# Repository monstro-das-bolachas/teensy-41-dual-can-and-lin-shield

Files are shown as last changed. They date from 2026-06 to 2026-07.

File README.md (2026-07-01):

# OBDee-Wan CANobi

> Open-hardware automotive bus interface for CAN FD, classic CAN, LIN, and K-line exploration.

OBDee-Wan CANobi is a Teensy 4.1 based vehicle-network tool for hackers, makers, reverse engineers, EV converters, and curious learners who want hardware they can inspect and understand.

It is designed as a practical bridge between a laptop and a vehicle or bench module: powerful enough for real CAN FD/LIN/K-line experiments, but documented as a teaching project rather than a black box.






## At a glance

| Area | Current R11 target |
| --- | --- |
| Host | Teensy 4.1 |
| CAN FD | 2 external CAN FD controller paths |
| Transceivers | Dual CAN FD transceivers |
| Other buses | LIN / K-line support path |
| Vehicle connection | OBD pigtail-friendly wiring, not a direct-plug dongle |
| Configuration | DIP-switch selectable routing options |
| CAD | KiCad hardware source and generated fabrication packages |
| Readiness | Bare-PCB prototype candidate for bench bring-up |

## What you can use it for

- CAN FD experimentation and learning
- Classic CAN diagnostics and reverse engineering
- LIN and K-line bench experiments
- EV conversion support tooling
- Custom diagnostic interface development
- Teaching automotive networks with inspectable hardware
- Bench testing ECUs, modules, sensors, and harness fragments

## Current status: R11 prototype manufacturing candidate

R11 may be ordered as a small bare-PCB prototype batch for bench bring-up.

It is not approved for direct vehicle testing yet.

### Active release package

`revisions/00_WORK_R11_TRUE_DUAL_CANFD/release/R11_PROTOTYPE_MANUFACTURING_CANDIDATE_20260630/`

### Manufacturer upload ZIP

`revisions/00_WORK_R11_TRUE_DUAL_CANFD/release/R11_PROTOTYPE_MANUFACTURING_CANDIDATE_20260630/package/JLCPCB_PCBWAY_UPLOAD_R11_MINIMAL_GERBERS_ONLY_20260630.zip`

SHA256:

`434dedf475bb3443f1ffa6384541426fcef9cf96a792c1744b9c1bb7ff68faa8`

### Verification summary

| Check | Result |
| --- | --- |
| KiCad CLI PCB DRC | 0 violations |
| Footprint errors | 0 |
| Known residual | 1 GND zone-to-zone report at 1.0000 mm / 1.0000 mm |
| Gerber/drill export | Successful |
| GND continuity | Visually confirmed in KiCad after refill/highlight |
| Vehicle-use approval | Not yet; bench validation required first |

The remaining GND item is a reviewed KiCad zone-report artifact for prototype PCB ordering. It is not a blanket safety approval for vehicle connection.

## Safety first

Vehicle electrical systems can damage tools, modules, or the car if connected incorrectly. Treat every first assembly as experimental hardware.

Before connecting to a vehicle:

1. Inspect the bare PCB.
2. Check for rail shorts with a multimeter.
3. Assemble and test the power section first.
4. Power up from a current-limited bench supply.
5. Verify OBD/pigtail pin mapping manually.
6. Confirm DIP-switch defaults and intended routing.
7. Test CAN/LIN/K behavior on bench modules first.
8. Use fusing and current limiting for any later vehicle test.

## Repository map

| Path | Purpose |
| --- | --- |
| `README_START_HERE.txt` | Short navigation and safety guide |
| `CURRENT_STATUS.md` | Current revision status, ordering notes, and verification summary |
| `revisions/00_WORK_R11_TRUE_DUAL_CANFD/` | Active R11 prototype candidate source and release package |
| `revisions/00_ACTIVE_R10_TRUE_DUAL_CANFD/` | Previous R10 archive, not for fabrication |
| `revisions/01_R9_CLASSIC_CAN_ARCHIVE/` | Historical R9 classic-CAN reference |
| `LICENSE` | Main hardware license: CERN-OHL-P-2.0 |
| `LICENSES/` | Full license texts and license split documentation |

## Recommended first order

For the first prototype batch, use conservative bare-board settings:

| Option | Recommendation |
| --- | --- |
| Quantity | 5 or smallest economical batch |
| Layers | 2 |
| Material | FR-4 |
| Thickness | 1.6 mm |
| Copper | 1 oz |
| Surface finish | Standard low-cost prototype finish is acceptable |
| Electrical test | Yes |
| Assembly | No; hand-assemble and validate first |

## Naming note

The project name is a small joke:

OBDee-Wan CANobi: an OBD/CAN interface that helps you feel disturbances in the bus.

## License

This project is open source and open hardware.

| Content | License |
| --- | --- |
| Hardware design files, KiCad sources, PCB/manufacturing files | CERN-OHL-P-2.0 |
| Firmware, scripts, and software | MIT |
| Documentation | CC-BY-4.0 |

You are free to study, modify, build, remix, and share this project. Attribution is required where applicable: please credit the original project and author when reusing or publishing derivative work.

See `LICENSES/README.md` for the full license split and SPDX identifiers.

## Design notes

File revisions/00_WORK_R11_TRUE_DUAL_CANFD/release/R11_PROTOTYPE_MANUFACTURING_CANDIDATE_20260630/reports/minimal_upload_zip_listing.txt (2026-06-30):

Archive:  /home/kali/teensy-r9-publish/revisions/00_WORK_R11_TRUE_DUAL_CANFD/release/R11_PROTOTYPE_MANUFACTURING_CANDIDATE_20260630/package/JLCPCB_PCBWAY_UPLOAD_R11_MINIMAL_GERBERS_ONLY_20260630.zip
  Length      Date    Time    Name
---------  ---------- -----   ----
   331847  2026-06-30 16:31   teensy-41-true-dual-canfd-lin-r11_JARVIS_ROUTED_CLEAN_V2_GND_STITCH-F_Cu.gtl
   207463  2026-06-30 16:31   teensy-41-true-dual-canfd-lin-r11_JARVIS_ROUTED_CLEAN_V2_GND_STITCH-B_Cu.gbl
     6726  2026-06-30 16:31   teensy-41-true-dual-canfd-lin-r11_JARVIS_ROUTED_CLEAN_V2_GND_STITCH-F_Mask.gts
     4547  2026-06-30 16:31   teensy-41-true-dual-canfd-lin-r11_JARVIS_ROUTED_CLEAN_V2_GND_STITCH-B_Mask.gbs
   138018  2026-06-30 16:31   teensy-41-true-dual-canfd-lin-r11_JARVIS_ROUTED_CLEAN_V2_GND_STITCH-F_Silkscreen.gto
    11956  2026-06-30 16:31   teensy-41-true-dual-canfd-lin-r11_JARVIS_ROUTED_CLEAN_V2_GND_STITCH-B_Silkscreen.gbo
      696  2026-06-30 16:31   teensy-41-true-dual-canfd-lin-r11_JARVIS_ROUTED_CLEAN_V2_GND_STITCH-Edge_Cuts.gm1
     3138  2026-06-30 16:31   teensy-41-true-dual-canfd-lin-r11_JARVIS_ROUTED_CLEAN_V2_GND_STITCH.drl
     5463  2026-06-30 16:31   teensy-41-true-dual-canfd-lin-r11_JARVIS_ROUTED_CLEAN_V2_GND_STITCH-job.gbrjob
---------                     -------
   709854                     9 files

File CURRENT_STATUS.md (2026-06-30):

# Current project status

Last checked/updated: 2026-06-30

## Executive summary

The active hardware revision is now **R11 true dual CAN FD + LIN/K prototype manufacturing candidate**.

R11 may be ordered as a small bare-PCB prototype batch for bench bring-up. It is **not approved for direct vehicle testing** until assembled boards pass continuity, power, pin-map, and fused OBD bench checks.

## Active R11 files

Active working revision folder:

- `revisions/00_WORK_R11_TRUE_DUAL_CANFD/`

Clean release package folder:

- `revisions/00_WORK_R11_TRUE_DUAL_CANFD/release/R11_PROTOTYPE_MANUFACTURING_CANDIDATE_20260630/`

Active KiCad source:

- `revisions/00_WORK_R11_TRUE_DUAL_CANFD/kicad/teensy-41-true-dual-canfd-lin-r11_JARVIS_ROUTED_CLEAN_V2_GND_STITCH.kicad_pcb`
- `revisions/00_WORK_R11_TRUE_DUAL_CANFD/kicad/teensy-41-true-dual-canfd-lin-r11_JARVIS_ROUTED_CLEAN_V2_GND_STITCH.kicad_pro`

JLCPCB / PCBWay upload ZIP:

- `revisions/00_WORK_R11_TRUE_DUAL_CANFD/release/R11_PROTOTYPE_MANUFACTURING_CANDIDATE_20260630/package/JLCPCB_PCBWAY_UPLOAD_R11_MINIMAL_GERBERS_ONLY_20260630.zip`

Full release ZIP:

- `revisions/00_WORK_R11_TRUE_DUAL_CANFD/release/R11_PROTOTYPE_MANUFACTURING_CANDIDATE_20260630/package/R11_PROTOTYPE_MANUFACTURING_CANDIDATE_20260630_FULL_RELEASE.zip`

## R11 verification

KiCad CLI DRC was run against the active board and the clean release-copy board.

Reports:

- `revisions/00_WORK_R11_TRUE_DUAL_CANFD/release/R11_PROTOTYPE_MANUFACTURING_CANDIDATE_20260630/reports/R11_PROTOTYPE_CANDIDATE_DRC.rpt`
- `revisions/00_WORK_R11_TRUE_DUAL_CANFD/release/R11_PROTOTYPE_MANUFACTURING_CANDIDATE_20260630/reports/R11_PROTOTYPE_CANDIDATE_CLEAN_RELEASE_COPY_DRC.rpt`

Result:

- DRC violations: 0
- Known residual: 1 GND F.Cu/B.Cu zone-to-zone unconnected report at 1.0000 mm / 1.0000 mm
- Footprint errors: 0
- Gerber/drill export: successful
- GND continuity: visually confirmed in KiCad after zone refill/highlight

The residual GND item is treated as a reviewed KiCad zone-report artifact for prototype PCB ordering, not as approval for vehicle use.

## R11 prototype ordering guidance

Order only a small bare-PCB batch first:

- 2 layers
- FR-4
- 1.6 mm
- 1 oz copper
- 5 pieces or smallest economical batch
- electrical test enabled
- no assembly for first order

Before vehicle testing:

1. Inspect bare PCBs.
2. Check GND continuity and rail shorts with a multimeter.
3. Assemble power section first.
4. Power from a current-limited bench supply.
5. Verify OBD/pigtail pin mapping with a multimeter.
6. Verify DIP switch safe/default positions.
7. Test CAN/LIN/K behavior on bench hardware before a fused OBD vehicle connection.

## R10/R9 status

R10 remains archived as `NOT FOR FAB` after external review. R9 remains historical/reference material only and is not true dual CAN FD.

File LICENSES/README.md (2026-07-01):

# Licensing

This project is open source and open hardware.

Copyright (c) 2026 Nuno Silva.

## License split

- Hardware design files, KiCad sources, PCB manufacturing outputs, and hardware documentation describing the design as source: `CERN-OHL-P-2.0`
- Firmware, scripts, examples, and other software source code: `MIT`
- Human-facing documentation, guides, diagrams, notes, and explanatory text: `CC-BY-4.0`

## What this means

You are welcome to study, build, modify, remix, repair, sell, and share derivatives of this project.

The main thing I ask — and the licenses require where applicable — is attribution: please credit the original project and author when reusing or publishing derivative work.

## SPDX identifiers

Use these SPDX identifiers when adding new files:

```text
SPDX-License-Identifier: CERN-OHL-P-2.0
```

for hardware design files.

```text
SPDX-License-Identifier: MIT
```

for firmware/software.

```text
SPDX-License-Identifier: CC-BY-4.0
```

for documentation.

## Full license texts

- `LICENSE` — CERN-OHL-P-2.0, the main repository hardware license.
- `LICENSES/CERN-OHL-P-2.0.txt`
- `LICENSES/MIT.txt`
- `LICENSES/CC-BY-4.0.txt`

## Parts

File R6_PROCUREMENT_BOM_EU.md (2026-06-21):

# R6 EU Procurement BOM

Status: procurement BOM for the corrected R6 manufacturing candidate.

Use this with the R6 board files, not the older R5 files.

Primary fabrication ZIP:

- `r6_complete_power_fabrication_minimal_gerbers.zip`

Procurement CSV:

- `BOM_R6_PROCUREMENT_EU.csv`

## Why R6 replaced R5

During BOM audit I found that R5 was DRC-clean but did not include the required external LM2596 buck-regulator components. R6 corrects this by adding:

- L1 buck inductor
- D2 Schottky catch diode
- C1 input electrolytic capacitor
- C3 output electrolytic capacitor
- C2/C4 ceramic input/output capacitors
- C5/C6/C7 local decoupling capacitors for CAN/LIN ICs
- R1 10k pull-up for the TLIN1029 open-drain LIN RXD output

R6 also changes the selected communication ICs to parts that are better aligned with Teensy 4.1 3.3 V logic:

- U2/U3: Microchip MCP2562FD-E/SN CAN transceivers with VIO on pin 5 connected to Teensy +3.3 V.
- U4: TI TLIN1029DRQ1 LIN transceiver, whose RXD is open-drain and pulled up to +3.3 V by R1.

## Suppliers

The BOM uses exact manufacturer part numbers. Suitable Europe-capable suppliers include:

- Mouser Europe
- DigiKey Europe
- Farnell / element14
- RS Components Europe
- TI store / MicrochipDirect where appropriate
- Pimoroni or other European PJRC/SparkFun distributors for Teensy 4.1

For best results, paste the exact MPN from the CSV into the supplier search box. Supplier stock numbers change more often than manufacturer part numbers.

## Critical no-substitution rules

Do not blindly substitute these parts:

- U2/U3 CAN transceivers: must have VIO/3.3 V I/O support on pin 5. Do not use MCP2551, TJA1050, or plain 5 V-only CAN transceivers.
- U4 LIN transceiver: must match TLIN1029DRQ1 SOIC-8 pinout if using this PCB.
- U5 regulator: must be fixed 5 V LM2596S-5.0 in TO-263-5/D2PAK-style package, not the adjustable version, unless the PCB is redesigned.
- SW1/SW2 DIP switches: must be 8-position SPST through-hole DIP, 2.54 mm pitch, 7.62 mm row spacing.
- C1/C3 electrolytics: observe polarity and keep diameter/lead pitch compatible with the footprint.

## Assembly order recommendation

1. Solder power/protection parts first: F1, D1, U5, L1, D2, C1, C2, C3, C4.
2. Bench-test the board from a current-limited 12 V supply.
3. Verify +5 V at TP2 and +3.3 V from the Teensy socket only after the Teensy is installed/powered appropriately.
4. Solder R1, C5/C6/C7, U2/U3/U4.
5. Solder SW1/SW2 and optional J2.
6. Install/socket Teensy 4.1 last.
7. Verify OBD pigtail pin numbering with a multimeter before connecting to a vehicle.

## Vehicle-use warning

This is still a first real hardware prototype. Even with a DRC-clean PCB and procurement BOM, test on the bench before connecting to a vehicle. Start with read-only/silent CAN firmware and no CAN transmission.

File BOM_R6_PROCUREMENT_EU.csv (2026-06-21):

Designator | Qty | Category | Exact MPN / Orderable Part | Manufacturer | Package / Footprint | Primary EU-capable supplier | Search / Supplier note | Substitution constraints | Assembly note
U1 | 1 | MCU module | DEV-16771 / Teensy 4.1 | SparkFun / PJRC | Teensy 4.1 module | Digikey / Mouser / Pimoroni / PJRC | Search supplier for DEV-16771 or PJRC Teensy 4.1 | Must be Teensy 4.1 not Teensy 4.0; socket recommended | Install after verifying 5V rail
U2 U3 | 2 | CAN transceiver | MCP2562FD-E/SN | Microchip | SOIC-8 3.9x4.9mm P1.27 | Mouser EU / DigiKey EU | Search exact MPN MCP2562FD-E/SN | Must have VIO pin on pin 5 for 3.3V Teensy I/O; do not substitute MCP2551/TJA1050 | Tin SOIC pads lightly; observe pin 1
U4 | 1 | LIN transceiver | TLIN1029DRQ1 | Texas Instruments | SOIC-8 D package | Mouser EU / DigiKey EU / TI store | Search exact MPN TLIN1029DRQ1 | Pinout must match TLIN1029 SOIC-8: RXD1 EN2 NC3 TXD4 GND5 LIN6 VSUP7 NC8; RXD is open-drain | Observe pin 1; R1 is required pull-up
U5 | 1 | 5V buck regulator | LM2596S-5.0/NOPB | Texas Instruments | TO-263-5 TabPin3 | Mouser EU / DigiKey EU | Search exact MPN LM2596S-5.0/NOPB | Fixed 5V TO-263/D2PAK version; do not use adjustable LM2596 without redesign | Large tab needs heat/ground copper; inspect solder joints
L1 | 1 | Buck inductor | RLB0914-330KL | Bourns | Radial inductor approx 33uH 5mm pitch | Mouser EU / DigiKey EU | Search exact MPN RLB0914-330KL | 33uH radial inductor; choose equal/higher current rating and compatible lead pitch if substituting | Keep upright and mechanically stable
D1 | 1 | Automotive input TVS | SMBJ24CA | Littelfuse / Bourns / Vishay | SMA / DO-214AA | Mouser EU / DigiKey EU / Farnell | Search exact MPN SMBJ24CA | Use bidirectional 24V standoff automotive/SMBJ-class TVS or equivalent SMA footprint | Polarity not critical if CA bidirectional
D2 | 1 | Buck Schottky diode | B340A-13-F | Diodes Inc | SMA / DO-214AC | Mouser EU / DigiKey EU / Farnell | Search exact MPN B340A-13-F | Use 3A or higher Schottky in SMA footprint; voltage rating >=40V | Observe polarity
F1 | 1 | Resettable fuse | MF-NSMF050-2 | Bourns | 1206 resettable PTC | Mouser EU / DigiKey EU / Farnell | Search exact MPN MF-NSMF050-2 | Hold current around 500mA; 1206 footprint | Solder before power tests
C1 | 1 | Input electrolytic capacitor | EEU-FR1H101 | Panasonic | Radial electrolytic 100uF 50V D8 P3.5 | Mouser EU / DigiKey EU / Farnell | Search exact MPN EEU-FR1H101 | 100uF 50V low-ESR radial; diameter <=8mm; lead pitch 3.5mm preferred | Observe polarity
C3 | 1 | Output electrolytic capacitor | EEU-FR1C331 | Panasonic | Radial electrolytic 330uF 16V D8 P3.5 | Mouser EU / DigiKey EU / Farnell | Search exact MPN EEU-FR1C331 | 330uF 16V or higher low-ESR radial; diameter <=8mm; lead pitch 3.5mm preferred | Observe polarity
C2 C4 C5 C6 C7 | 5 | Ceramic decoupling capacitor | C0805C104K5RACTU | KEMET | 0805 X7R 100nF 50V | Mouser EU / DigiKey EU / Farnell | Search exact MPN C0805C104K5RACTU | 100nF 50V X7R 0805; any reputable equivalent OK | Small SMD; use flux
R1 | 1 | LIN RX pull-up resistor | RC0805FR-0710KL | Yageo | 0805 resistor 10k 1% | Mouser EU / DigiKey EU / Farnell | Search exact MPN RC0805FR-0710KL | 10k 0805 1% or 5% OK | Required for TLIN1029 open-drain RXD
SW1 SW2 | 2 | 8-position DIP switch | 219-8MST | CTS Electrocomponents | 8-position SPST DIP through-hole 2.54mm pitch 7.62mm row | Mouser EU / DigiKey EU / Farnell | Search exact MPN 219-8MST | Must be 8-position SPST through-hole DIP matching KiCad SW_DIP_SPSTx08 W7.62 P2.54 | Install readable ON orientation
J2 | 1 | Aux header | TSW-108-07-G-S | Samtec | 1x8 2.54mm vertical header | Mouser EU / DigiKey EU / Farnell | Search exact MPN TSW-108-07-G-S | Any 1x8 2.54mm vertical male header acceptable | Optional if aux access needed
J1 off-board | 1 | OBD2 male pigtail / connector | RS 179-7873 or equivalent | RS PRO / equivalent | Off-board OBD2/J1962 male with wires | RS Components Europe | Use RS stock number 1797873 if it matches desired OBD2 connector/cable | Must verify actual pin numbering and wire colors with multimeter before vehicle use | Solder wires to J1 pads; use strain relief holes
U1 headers | 1 set | Teensy 4.1 socket/header strips | Generic 2.54mm female headers | Various | 2.54mm headers | Mouser / DigiKey / Pimoroni / local EU electronics shop | Use quality breakaway female socket strips | Use sockets if you want removable Teensy | Cut to fit Teensy side rows
MH1-MH4 | 4 | Mounting hardware | M3 screw/standoff kit | Generic | M3 hardware | Local EU hardware / Amazon EU / RS | Not soldered | Non-conductive standoffs preferred | Optional
SR1-SR2 | 2 | Cable strain relief | Small zip ties | Generic | Through board strain relief holes | Local EU hardware / Amazon EU / RS | Not soldered | Use around OBD cable jacket | Required for pigtail durability

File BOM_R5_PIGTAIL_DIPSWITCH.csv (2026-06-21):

Reference | Quantity | Value / Part | Footprint | Notes
U1 | 1 | Teensy 4.1 module | Project local Teensy_4.1_MainHeaders_PJRC_Audited | Install using 2.54 mm headers/socket strips; USB accessible from Teensy itself
U2 | 1 | TJA1051 CAN transceiver SOIC-8 | SOIC-8_3.9x4.9mm_P1.27mm | CAN A transceiver; verify exact variant supply/standby behavior before assembly
U3 | 1 | TJA1051 CAN transceiver SOIC-8 | SOIC-8_3.9x4.9mm_P1.27mm | CAN B transceiver; verify exact variant supply/standby behavior before assembly
U4 | 1 | TJA1021 LIN transceiver SOIC-8 | SOIC-8_3.9x4.9mm_P1.27mm | LIN/K transceiver candidate; K-Line protocol compatibility should be firmware/bench tested
U5 | 1 | LM2596S-5 buck regulator | TO-263-5_TabPin3 | 5 V regulator footprint; verify BOM/package/pinout for exact purchased part
SW1 | 1 | 8-position SPST DIP switch | SW_DIP_SPSTx08_Slide_9.78x22.5mm_W7.62mm_P2.54mm | CAN normal/cross selector
SW2 | 1 | 8-position SPST DIP switch | SW_DIP_SPSTx08_Slide_9.78x22.5mm_W7.62mm_P2.54mm | LIN/K source selector; select one only
J1 | 1 | OBD2 pigtail solder pads | Project local OBD2_PigtailPads_Manufacturing | Solder OBD male cable wires directly; use strain relief holes
J2 | 1 | 1x8 2.54 mm header | PinHeader_1x08_P2.54mm_Vertical | Auxiliary CAN/LIN/power header
F1 | 1 | 500 mA resettable polyfuse | Fuse_1206_3216Metric | Automotive 12 V input protection
D1 | 1 | SMBJ24CA or similar automotive TVS | D_SMA | 12 V transient clamp; verify standoff/clamp rating
TP1 | 1 | 12 V test pad | TestPoint_Pad_D1.5mm | Test point
TP2 | 1 | 5 V test pad | TestPoint_Pad_D1.5mm | Test point
TP3 | 1 | GND test pad | TestPoint_Pad_D1.5mm | Test point
TP4 | 1 | CAN_A_H test pad | TestPoint_Pad_D1.5mm | Test point
TP5 | 1 | CAN_A_L test pad | TestPoint_Pad_D1.5mm | Test point
TP6 | 1 | CAN_B_H test pad | TestPoint_Pad_D1.5mm | Test point
TP7 | 1 | CAN_B_L test pad | TestPoint_Pad_D1.5mm | Test point
TP8 | 1 | LIN_BUS test pad | TestPoint_Pad_D1.5mm | Test point
TP9 | 1 | AUX_LIN_K_IO test pad | TestPoint_Pad_D1.5mm | Test point
MH1-MH4 | 4 | M3 mounting holes | MountingHole_3.2mm_M3 | Board mounting
SR1-SR2 | 2 | Cable strain relief holes | MountingHole_3.2mm_M3 | Use zip tie around OBD cable
OBD cable | 1 | OBD2 male pigtail cable or connector with wires | Off-board part | Example approach: RS-style automotive OBD connector/cable; verify each wire with multimeter
Headers/socket | 1 set | 2.54 mm female/male headers for Teensy | Off-board part | Choose socketing method before assembly

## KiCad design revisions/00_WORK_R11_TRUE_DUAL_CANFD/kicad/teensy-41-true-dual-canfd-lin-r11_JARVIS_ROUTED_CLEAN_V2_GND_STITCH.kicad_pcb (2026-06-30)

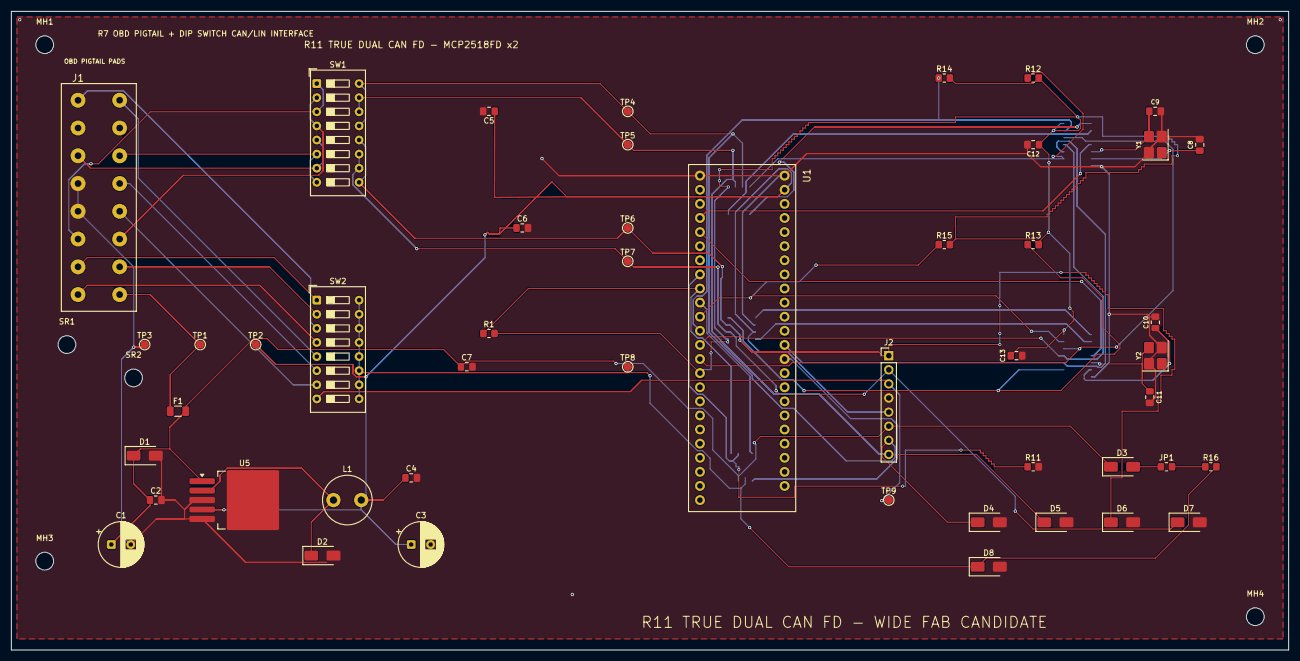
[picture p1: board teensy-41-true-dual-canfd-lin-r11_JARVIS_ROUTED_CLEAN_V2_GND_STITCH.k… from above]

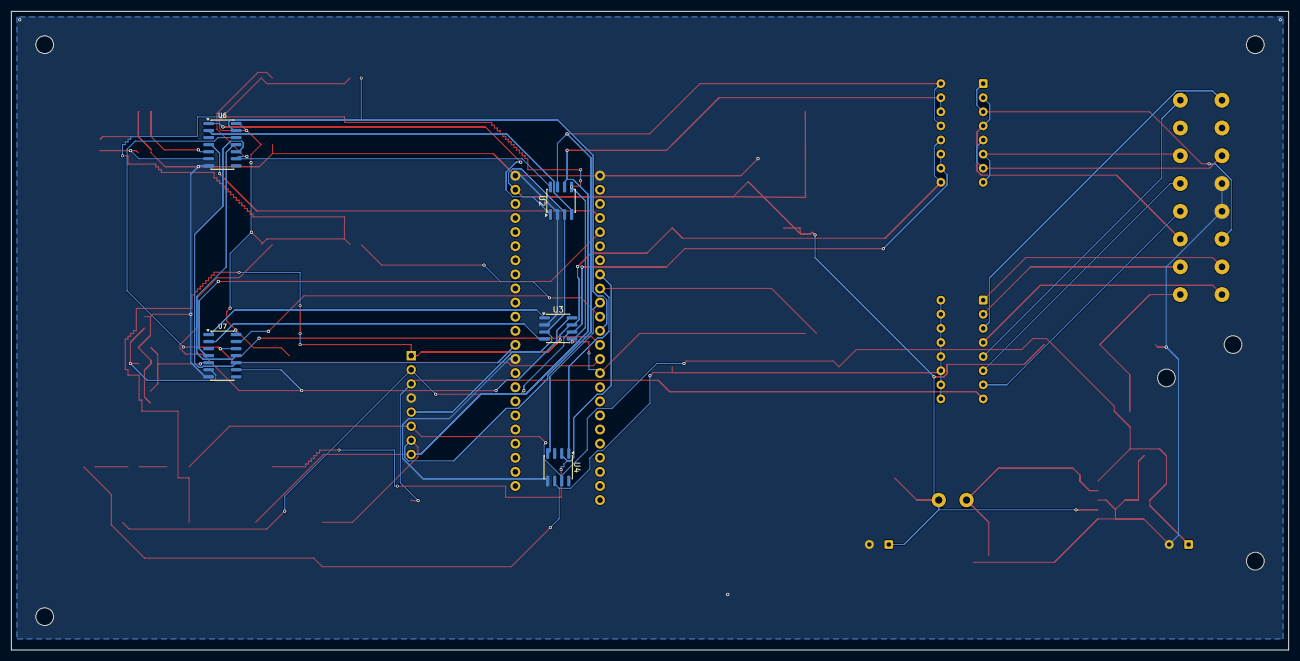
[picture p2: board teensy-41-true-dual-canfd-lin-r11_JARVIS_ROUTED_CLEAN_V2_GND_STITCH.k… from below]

Board: 2 copper layers, 230.0 x 115.0 mm, 59 parts (5 on the bottom side), 45 nets.

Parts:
C1: 100uF_50V_INPUT; CP_Radial_D8.0mm_P3.50mm
C2: 100nF_50V_INPUT; C_0805_2012Metric_Pad1.18x1.45mm_HandSolder
C3: 330uF_16V_OUTPUT_LOW_ESR; CP_Radial_D8.0mm_P3.50mm
C4: 100nF_16V_OUTPUT; C_0805_2012Metric_Pad1.18x1.45mm_HandSolder
C5: 100nF_CAN_A_VDD_LOCAL; C_0805_2012Metric_Pad1.18x1.45mm_HandSolder
C6: 100nF_CAN_B_VDD_LOCAL; C_0805_2012Metric_Pad1.18x1.45mm_HandSolder
C7: 100nF_LIN_VSUP_LOCAL; C_0805_2012Metric_Pad1.18x1.45mm_HandSolder
C8: 22pF_Y1_OSC1; C_0805_2012Metric_Pad1.18x1.45mm_HandSolder
C9: 22pF_Y1_OSC2; C_0805_2012Metric_Pad1.18x1.45mm_HandSolder
C10: 22pF_Y2_OSC1; C_0805_2012Metric_Pad1.18x1.45mm_HandSolder
C11: 22pF_Y2_OSC2; C_0805_2012Metric_Pad1.18x1.45mm_HandSolder
C12: 100nF_U6_VDD_LOCAL; C_0805_2012Metric_Pad1.18x1.45mm_HandSolder
C13: 100nF_U7_VDD_LOCAL; C_0805_2012Metric_Pad1.18x1.45mm_HandSolder
D1: SMBJ24CA_TVS_12V; D_SMA
D2: SS34_BUCK_SCHOTTKY; D_SMA
D3: LIN_MASTER_PULLUP_DIODE_DNP; D_SMA
D4: ESD_CAN_A_H_TVS_VERIFY; D_SMA
D5: ESD_CAN_A_L_TVS_VERIFY; D_SMA
D6: ESD_CAN_B_H_TVS_VERIFY; D_SMA
D7: ESD_CAN_B_L_TVS_VERIFY; D_SMA
D8: ESD_LIN_K_TVS_VERIFY; D_SMA
F1: POLYFUSE_500mA; Fuse_1206_3216Metric
J1: OBD2_PIGTAIL_16_WIRE_SOLDER_PADS; OBD2_PigtailPads_Manufacturing
J2: AUX_HEADER; PinHeader_1x08_P2.54mm_Vertical
JP1: LIN_MASTER_ENABLE_OPEN_0R_DNP; R_0805_2012Metric_Pad1.20x1.40mm_HandSolder
L1: 33uH_3A_BUCK_INDUCTOR; L_Radial_D8.7mm_P5.00mm_Fastron_07HCP
MH1, MH2, MH3, MH4: M3; MountingHole_3.2mm_M3
R1: 10k_LIN_RX_PULLUP; R_0805_2012Metric_Pad1.20x1.40mm_HandSolder
R11: 100k_LIN_EN_PULLDOWN; R_0805_2012Metric_Pad1.20x1.40mm_HandSolder
R12: 10k_CAN_A_STBY_PULLUP; R_0805_2012Metric_Pad1.20x1.40mm_HandSolder
R13: 10k_CAN_B_STBY_PULLUP; R_0805_2012Metric_Pad1.20x1.40mm_HandSolder
R14: 10k_CANFD_A_NCS_PULLUP; R_0805_2012Metric_Pad1.20x1.40mm_HandSolder
R15: 10k_CANFD_B_NCS_PULLUP; R_0805_2012Metric_Pad1.20x1.40mm_HandSolder
R16: 1k_LIN_MASTER_PULLUP_DNP; R_0805_2012Metric_Pad1.20x1.40mm_HandSolder
SR1, SR2: CABLE_STRAIN_RELIEF; MountingHole_3.2mm_M3
SW1: CAN_NORMAL_CROSS_DIP_8POS; SW_DIP_SPSTx08_Slide_9.78x22.5mm_W7.62mm_P2.54mm
SW2: LIN_K_SOURCE_DIP_8POS_SELECT_ONE; SW_DIP_SPSTx08_Slide_9.78x22.5mm_W7.62mm_P2.54mm
TP1: 12V; TestPoint_Pad_D1.5mm
TP2: 5V; TestPoint_Pad_D1.5mm
TP3: GND; TestPoint_Pad_D1.5mm
TP4: CAN_A_H; TestPoint_Pad_D1.5mm
TP5: CAN_A_L; TestPoint_Pad_D1.5mm
TP6: CAN_B_H; TestPoint_Pad_D1.5mm
TP7: CAN_B_L; TestPoint_Pad_D1.5mm
TP8: LIN_BUS; TestPoint_Pad_D1.5mm
TP9: AUX_LIN_K; TestPoint_Pad_D1.5mm
U1: TEENSY_4.1_MAIN_HEADERS_PJRC_AUDITED; Teensy_4.1_MainHeaders_PJRC_Audited
U2: MCP2562FD_CAN_A_3V3_IO; SOIC-8_3.9x4.9mm_P1.27mm
U3: MCP2562FD_CAN_B_3V3_IO; SOIC-8_3.9x4.9mm_P1.27mm
U4: TLIN1029DRQ1_LIN_3V3_LOGIC; SOIC-8_3.9x4.9mm_P1.27mm
U5: LM2596S-5.0_BUCK; TO-263-5_TabPin3
U6: MCP2518FD_A_SOIC14; SOIC-14_3.9x8.7mm_P1.27mm
U7: MCP2518FD_B_SOIC14; SOIC-14_3.9x8.7mm_P1.27mm
Y1, Y2: 40MHz_3225_VERIFY_CL; Crystal_SMD_3225-4Pin_3.2x2.5mm_HandSoldering

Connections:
+3V3: C12.1, C13.1, R1.2, R12.2, R13.2, R14.2, R15.2, U1.3V3_B, U2.5, U3.5, U6.14, U7.14
+5V_REGULATED: C3.1, C4.1, C5.1, C6.1, J2.5, L1.2, TP2.1, U1.VIN, U2.3, U3.3, U5.4
+12V_OBD: F1.1, J1.16, TP1.1
+12V_PROTECTED: C1.1, C2.1, C7.1, D1.1, D3.1, F1.2, J2.6, U4.7, U5.1
AUX_LIN_K_IO: J2.3, SW2.8, TP9.1
BUCK_SW: D2.1, L1.1, U5.2
CANFD_A_INT: U1.2, U6.4
CANFD_A_NCS: R14.1, U1.10, U6.13
CANFD_A_OSC1: C8.1, U6.6, Y1.1
CANFD_A_OSC2: C9.1, U6.5, Y1.3
CANFD_A_RXCAN: U2.4, U6.2
CANFD_A_TXCAN: U2.1, U6.1
CANFD_A_XSTBY: R12.1, U2.8, U6.9
CANFD_B_INT: U1.3, U7.4
CANFD_B_NCS: R15.1, U1.9, U7.13
CANFD_B_OSC1: C10.1, U7.6, Y2.1
CANFD_B_OSC2: C11.1, U7.5, Y2.3
CANFD_B_RXCAN: U3.4, U7.2
CANFD_B_TXCAN: U3.1, U7.1
CANFD_B_XSTBY: R13.1, U3.8, U7.9
CANFD_SPI_SCK: U1.13, U6.10, U7.10
CANFD_SPI_SDI_MOSI: U1.11, U6.11, U7.11
CANFD_SPI_SDO_MISO: U1.12, U6.12, U7.12
CAN_A_H: D4.1, J2.7, SW1.13, SW1.16, TP4.1, U2.7
CAN_A_L: D5.1, J2.8, SW1.14, SW1.15, TP5.1, U2.6
CAN_B_H: D6.1, J2.1, SW1.9, SW1.12, TP6.1, U3.7
CAN_B_L: D7.1, J2.2, SW1.10, SW1.11, TP7.1, U3.6
GND: C1.2, C2.2, C3.2, C4.2, C5.2, C6.2, C7.2, C8.2, C9.2, C10.2, C11.2, C12.2, C13.2, D1.2, D2.2, D4.2, D5.2, D6.2, D7.2, D8.2, J1.4, J1.5, J2.4, R11.2, TP3.1, U1.GND_B1, U1.GND_T1, U1.GND_T2, U2.2, U3.2, U4.5, U5.3, U5.5, U6.7, U7.7, Y1.2, Y1.4, Y2.2, Y2.4
LIN_BUS: D8.1, R16.2, SW2.9, SW2.10, SW2.11, SW2.12, SW2.13, SW2.14, SW2.15, SW2.16, TP8.1, U4.6
LIN_EN: R11.1, U1.6, U4.2
LIN_MASTER_DIODE_OUT: D3.2, JP1.1
LIN_MASTER_ENABLE: JP1.2, R16.1
LIN_RX: R1.1, U1.7, U4.1
LIN_TX: U1.8, U4.4
OBD1_SINGLE_WIRE_CANDIDATE: J1.1, SW2.3
OBD3_CAN_B_PAIR_A_CANDIDATE: J1.3, SW1.5, SW1.7
OBD6_CAN_A_PAIR_A: J1.6, SW1.1, SW1.3
OBD7_SINGLE_WIRE_CANDIDATE: J1.7, SW2.1
OBD8_SINGLE_WIRE_CANDIDATE: J1.8, SW2.4
OBD9_SINGLE_WIRE_CANDIDATE: J1.9, SW2.5
OBD11_CAN_B_PAIR_B_CANDIDATE: J1.11, SW1.6, SW1.8
OBD12_SINGLE_WIRE_CANDIDATE: J1.12, SW2.6
OBD13_SINGLE_WIRE_CANDIDATE: J1.13, SW2.7
OBD14_CAN_A_PAIR_B: J1.14, SW1.2, SW1.4
OBD15_SINGLE_WIRE_CANDIDATE: J1.15, SW2.2

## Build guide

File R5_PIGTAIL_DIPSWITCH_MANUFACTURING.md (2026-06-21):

# R5 pigtail + DIP-switch manufacturing package

Last updated: 2026-06-21

## Status

R5 is the current manufacturing candidate for the Teensy 4.1 CAN/LIN automotive interface.

Authoritative routed PCB:

- `teensy-41-can-lin-r5-pigtail-dipswitch-routed.kicad_pcb`

KiCad verification:

- KiCad CLI: 10.0.3
- DRC violations: 0
- Unconnected pads: 0
- Footprint errors: 0
- SVG preview export: passed
- Gerber/drill export: passed

Preferred fabrication ZIP:

- `r5_pigtail_dipswitch_fabrication_minimal_gerbers.zip`

Full KiCad layer export ZIP, kept for reference:

- `r5_pigtail_dipswitch_fabrication_gerbers.zip`

## What changed from R4

R5 removes the risky board-mounted OBD2/J1962 connector footprint and replaces it with robust pigtail/cable solder pads.

R5 also replaces solder-jumper routing selectors with DIP switches:

- `SW1`: CAN normal/cross routing selector
- `SW2`: LIN/K single-wire source selector

This makes the board easier to configure without soldering/desoldering jumpers.

## Mechanical approach

Instead of mounting an OBD connector directly to the PCB:

1. Use an OBD2 male pigtail cable or OBD2 male connector with cable.
2. Solder each OBD wire to the matching labeled PCB pad.
3. Use the two strain-relief holes near the cable entry with a zip tie.
4. Put the OBD connector at the vehicle end of the cable.

This avoids the previous mechanical blocker: no exact board-mounted OBD connector datasheet was available.

## OBD pigtail pad mapping

The board uses J1962/OBD2 pin numbers at `J1`:

| OBD pin | Board net / purpose |
| --- | --- |
| 1 | Single-wire candidate |
| 2 | PWM/J1850 spare candidate |
| 3 | CAN B pair A candidate |
| 4 | Ground |
| 5 | Ground |
| 6 | CAN A pair A / standard CAN-H candidate |
| 7 | K-Line / LIN/K single-wire candidate |
| 8 | Single-wire candidate |
| 9 | Single-wire candidate |
| 10 | PWM/J1850 spare candidate |
| 11 | CAN B pair B candidate |
| 12 | Single-wire candidate |
| 13 | Single-wire candidate |
| 14 | CAN A pair B / standard CAN-L candidate |
| 15 | L-Line / LIN/K single-wire candidate |
| 16 | +12 V battery input |

## Teensy 4.1 pin audit

The Teensy footprint used in R5 was audited against the PJRC Teensy 4.1 pinout card.

Main assignments:

| Function | Teensy pin |
| --- | --- |
| CAN A TX / CTX1 | 22 |
| CAN A RX / CRX1 | 23 |
| CAN B TX / CTX2 | 1 |
| CAN B RX / CRX2 | 0 |
| LIN/K UART TX | 8 |
| LIN/K UART RX | 7 |
| CAN A standby/control | 5 |
| CAN B standby/control | 4 |
| LIN enable/control | 6 |
| VIN from board 5 V rail | VIN |
| Ground | GND |

Important PJRC facts used:

- Main side headers: two long rows, 24 pins each.
- Header pitch: 2.54 mm.
- Row spacing: 15.24 mm / 0.6 inch.
- PJRC hole guidance: 0.965 mm finished hole diameter for the main through-hole locations.
- Teensy 4.1 I/O is not 5 V tolerant.

## DIP switch configuration

### SW1: CAN normal/cross selector

`SW1` is an 8-position SPST DIP switch.

| SW1 position | Function |
| --- | --- |
| 1 | CAN A normal: OBD6 -> CAN_A_H |
| 2 | CAN A normal: OBD14 -> CAN_A_L |
| 3 | CAN A crossed: OBD6 -> CAN_A_L |
| 4 | CAN A crossed: OBD14 -> CAN_A_H |
| 5 | CAN B normal: OBD3 -> CAN_B_H |
| 6 | CAN B normal: OBD11 -> CAN_B_L |
| 7 | CAN B crossed: OBD3 -> CAN_B_L |
| 8 | CAN B crossed: OBD11 -> CAN_B_H |

Safe defaults:

- For standard OBD CAN on pins 6/14: turn ON SW1-1 and SW1-2 only.
- For CAN A crossed test: turn ON SW1-3 and SW1-4 only.
- For CAN B normal candidate: turn ON SW1-5 and SW1-6 only.
- For CAN B crossed candidate: turn ON SW1-7 and SW1-8 only.
- Never enable normal and crossed for the same CAN bus at the same time.

### SW2: LIN/K source selector

`SW2` is an 8-position SPST DIP switch.

| SW2 position | Source connected to LIN/K transceiver bus |
| --- | --- |
| 1 | OBD7 |
| 2 | OBD15 |
| 3 | OBD1 |
| 4 | OBD8 |
| 5 | OBD9 |
| 6 | OBD12 |
| 7 | OBD13 |
| 8 | AUX_LIN_K_IO |

Safe defaults:

- Turn ON exactly one SW2 position at a time.
- Typical legacy diagnostic test: SW2-1 ON for OBD7.
- Older/variant L-line test: SW2-2 ON for OBD15.
- Leave all SW2 switches OFF until the target vehicle pin is known.

## Before connecting to a vehicle

1. Inspect the manufactured PCB visually.
2. Check for solder bridges with a magnifier.
3. With no Teensy installed, power from current-limited bench supply first.
4. Verify +5 V rail before installing Teensy.
5. Confirm OBD cable wiring with a multimeter pin-by-pin.
6. Confirm SW1/SW2 settings before plugging into the car.
7. Start with passive/read-only firmware.
8. Do not enable CAN termination unless you intentionally need it.

## Manufacturing notes

Recommended PCB fab settings:

- 2-layer FR4
- 1.6 mm thickness
- 1 oz copper
- HASL or ENIG acceptable
- Solder mask: any color
- Silkscreen: white recommended

The Gerber ZIP was generated by KiCad CLI from the DRC-clean routed board. It is suitable for PCB fabrication upload.

Assembly still requires correct component procurement and soldering. The PCB files do not purchase parts automatically.

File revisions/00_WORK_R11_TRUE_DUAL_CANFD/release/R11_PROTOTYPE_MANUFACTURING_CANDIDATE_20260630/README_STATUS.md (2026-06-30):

# R11 status

Status: PROTOTYPE_MANUFACTURING_CANDIDATE.

This revision is suitable for ordering a small bare-PCB prototype batch for bench bring-up. It is not approved for direct vehicle testing yet.

Active board:
`kicad/teensy-41-true-dual-canfd-lin-r11_JARVIS_ROUTED_CLEAN_V2_GND_STITCH.kicad_pcb`

Manufacturing upload ZIP:
`package/JLCPCB_PCBWAY_UPLOAD_R11_MINIMAL_GERBERS_ONLY_20260630.zip`

Full release archive:
`package/R11_PROTOTYPE_MANUFACTURING_CANDIDATE_20260630_FULL_RELEASE.zip`

Verification:
- KiCad CLI DRC: 0 DRC violations.
- Known residual: 1 GND zone-to-zone unconnected report at 1.0000 mm / 1.0000 mm.
- GND continuity: visually confirmed in KiCad by user after zone refill/highlight.
- Gerber/drill export: completed by KiCad CLI.

Do not use on a vehicle until:
1. Bare PCB continuity is checked.
2. Power rails are checked for shorts.
3. Board is powered from current-limited bench supply.
4. OBD/pigtail pin mapping is verified with a multimeter.
5. DIP switch default-safe positions are documented and confirmed.
6. CAN/LIN/K-line behavior is tested on bench hardware first.

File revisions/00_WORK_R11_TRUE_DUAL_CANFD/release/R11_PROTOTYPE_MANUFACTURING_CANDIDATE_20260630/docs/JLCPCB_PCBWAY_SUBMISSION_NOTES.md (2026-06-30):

# R11 prototype PCB submission notes

Status: PROTOTYPE_MANUFACTURING_CANDIDATE, not vehicle-ready.

Use this upload ZIP for JLCPCB or PCBWay:

`package/JLCPCB_PCBWAY_UPLOAD_R11_MINIMAL_GERBERS_ONLY_20260630.zip`

Verification basis:
- KiCad CLI: see `reports/kicad_version.txt`
- Source board: `kicad/teensy-41-true-dual-canfd-lin-r11_JARVIS_ROUTED_CLEAN_V2_GND_STITCH.kicad_pcb`
- DRC report: `reports/R11_PROTOTYPE_CANDIDATE_DRC.rpt`
- DRC result: 0 DRC violations; 1 unconnected item remains, the known GND F.Cu/B.Cu zone self-report at 1.0000 mm / 1.0000 mm.
- User visually confirmed GND continuity in KiCad after refill/highlight.
- Gerbers/drill exported by KiCad CLI.

Recommended first order:
- Quantity: 5 PCBs, or smallest cheap prototype batch
- Layers: 2
- Material: FR-4
- Thickness: 1.6 mm
- Copper: 1 oz
- Finish: Lead-free HASL for cost, ENIG if price difference is acceptable
- Electrical test: yes / flying probe
- Assembly: no, bare PCBs only for first order
- Panelization: no

Portal preview checks before paying:
1. Board outline appears correct.
2. Top and bottom copper are visible.
3. Drill holes/vias are present.
4. No obvious copper shorts between OBD/pigtail pads.
5. Silkscreen labels do not cover pads critically.
6. If the portal warns about the known GND zone artifact, do not treat it as vehicle approval; it is only acceptable for prototype PCB manufacture because continuity was visually confirmed.

Bring-up warning:
- Do not connect the first assembled board directly to a vehicle.
- First test bare PCB continuity with a multimeter.
- Then assemble/power in stages with bench supply current limiting.
- Vehicle testing requires fused OBD pigtail and pin-map verification.

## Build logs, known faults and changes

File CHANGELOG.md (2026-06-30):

# Changelog

## 2026-06-30 — R10 status correction: NOT FOR FAB

- Reclassified R10 as an inspection/review revision only after external review.
- Confirmed R10 architecture is correct for true dual CAN FD, but not orderable.
- Added `R10_EXTERNAL_REVIEW_FINDINGS_20260630.md` with blockers for R10A/R11.
- Updated README/status files to warn not to send the R10 JLCPCB Gerber ZIP to fabrication.

## R10 true dual CAN FD active release - 2026-06-30

### Status

R10 is now the active cleaned hardware revision for the true dual CAN FD + LIN/K interface.

### Added

- Added cleaned active revision folder: `revisions/00_ACTIVE_R10_TRUE_DUAL_CANFD/`.
- Added canonical R10 KiCad source using MCP2518FD controllers and MCP2562FD transceivers.
- Added regenerated JLCPCB/root-upload Gerber ZIP: `R10_TRUE_DUAL_CANFD_JLCPCB_GERBERS.zip`.
- Added full R10 source/handoff ZIP: `R10_TRUE_DUAL_CANFD_FULL_PACKAGE.zip`.
- Added cleanup/reorganization manifests under `99_MANIFESTS/`.
- Added `README_START_HERE.txt` as the top-level project navigation file.

### Verification

R10 was verified from the cleaned active revision folder with KiCad CLI 10.0.3.

- DRC violations: 0
- Unconnected pads/items: 0
- Footprint errors: 0
- Gerber/drill export: passed

### Changed

- Reorganized the repository around explicit revision folders.
- Archived R9 under `revisions/01_R9_CLASSIC_CAN_ARCHIVE/`.
- Updated root README and current status to point to R10 as the active design.

### Removed from current branch layout

- Removed root-level test/draft/intermediate R10 KiCad files.
- Removed failed optimization artifacts.
- Removed FreeRouting scratch directories.
- Removed intermediate R10 DRC reports superseded by the cleaned-folder DRC recheck.
- Removed obsolete root `hardware/`, `docs/`, and `fabrication/` layout after valid contents were moved into revision folders.

## R10 true dual CAN FD target - 2026-06-29

### Status

The project requirement changed to **true dual CAN FD**. R9 is no longer the final target board; it is now bench-only/classic-CAN prototype material.

### Added

- Added R10 redesign planning documents.
- Added R10 MCP2518FD controller architecture notes.
- Updated R9 BOM/netlist docs so they are PCB-derived and no longer describe stale TJA1051/TJA1020/DB9/USB-C content as current hardware.

### Required for R10

- Add MCP2518FD CAN FD controller x2.
- Keep MCP2562FD transceiver x2.
- Route Teensy SPI + CS/INT/RESET to the controllers.
- Create authoritative schematic and updated BOM before any R10 fab-ready claim.

## Repository cleanup - 2026-06-22

### Changed

- Reorganized the public repository around the then-current R9 FAB_READY release.
- Moved authoritative KiCad source and local footprints to `hardware/kicad/`.
- Moved R9 Gerbers, reports, and release package to `fabrication/r9/`.
- Moved public user-facing hardware docs to `docs/`.

### Removed from current branch

- Removed intermediate R5/R6/R7 KiCad variants, Gerbers, preview SVGs, BOMs, and reports from the public tree.
- Removed all tracked generation scripts from the public repository.
- Removed firmware/code example file from the public repository to keep code/scripts private.

## R9 FAB_READY - 2026-06-22

### Status

R9 was the manufacturing prototype candidate for the Teensy 4.1 dual classic CAN + LIN/K automotive interface using CAN-FD-capable transceivers. After the 2026-06-29 true-FD decision, R9 is no longer the final target board.

### Added

- Added explicit R9 final-candidate KiCad PCB/project files.
- Added clean FAB_READY manufacturing ZIP.
- Added R9 Gerber/drill outputs.
- Added R9 verification reports.
- Added project-local footprint library support.

### Verification

R9 was verified from the cleaned project copy with KiCad CLI 10.0.3.

- DRC violations: 0
- Unconnected pads/items: 0
- Footprint errors: 0
- Gerber/drill export: passed

### Notes

- The legacy schematic is not authoritative for R9. Manufacturing confidence is based on the KiCad PCB source, project-local footprints, KiCad CLI DRC, and KiCad-generated Gerber/drill files.
- R9 remains first-run prototype/reference hardware: order a small batch only if intentionally testing the older classic-CAN architecture, bench-test power rails first, start with passive/read-only firmware, and verify the OBD2 pigtail pinout with a multimeter.

## Earlier intermediate revisions

R5, R6, and R7 were development/intermediate variants leading to R9. They are no longer tracked in the current public branch layout.

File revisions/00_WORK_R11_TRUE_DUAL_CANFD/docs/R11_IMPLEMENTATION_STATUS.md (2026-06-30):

# R11 implementation status

Status: PROTOTYPE_MANUFACTURING_CANDIDATE for small bare-PCB bench bring-up batch.
Vehicle status: NOT VEHICLE-READY.

## Active source

- `../kicad/teensy-41-true-dual-canfd-lin-r11_JARVIS_ROUTED_CLEAN_V2_GND_STITCH.kicad_pcb`
- `../kicad/teensy-41-true-dual-canfd-lin-r11_JARVIS_ROUTED_CLEAN_V2_GND_STITCH.kicad_pro`

## Release package

- `../release/R11_PROTOTYPE_MANUFACTURING_CANDIDATE_20260630/`

Use this manufacturer upload ZIP:

- `../release/R11_PROTOTYPE_MANUFACTURING_CANDIDATE_20260630/package/JLCPCB_PCBWAY_UPLOAD_R11_MINIMAL_GERBERS_ONLY_20260630.zip`

## KiCad verification

Reports:

- `../release/R11_PROTOTYPE_MANUFACTURING_CANDIDATE_20260630/reports/R11_PROTOTYPE_CANDIDATE_DRC.rpt`
- `../release/R11_PROTOTYPE_MANUFACTURING_CANDIDATE_20260630/reports/R11_PROTOTYPE_CANDIDATE_CLEAN_RELEASE_COPY_DRC.rpt`

Result:

- DRC violations: 0
- Footprint errors: 0
- Known residual: one GND zone-to-zone unconnected report at 1.0000 mm / 1.0000 mm
- GND continuity: visually confirmed in KiCad after zone refill/highlight
- Gerbers/drill: exported successfully by KiCad CLI

## Safety status

Acceptable next step:

- Order a small bare-PCB prototype batch for bench bring-up.

Not acceptable yet:

- Do not order assembly.
- Do not connect to a vehicle.
- Do not call this final/fab-ready for general use.

Before vehicle testing, verify bare board continuity, power rails, OBD/pigtail pin mapping, DIP switch defaults, CAN/LIN/K behavior on bench hardware, and fused OBD connection procedure.

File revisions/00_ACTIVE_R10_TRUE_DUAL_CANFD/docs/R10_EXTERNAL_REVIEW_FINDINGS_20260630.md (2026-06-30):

# R10 external review findings — NOT FOR FAB — 2026-06-30

Status: **R10 is not fabrication-ready. Do not order R10 boards.**

The external review confirms that R10 fixed the major architectural error: it now uses two MCP2518FD CAN FD controllers between the Teensy 4.1 SPI bus and two MCP2562FD CAN FD transceivers. That is the correct high-level architecture for true dual CAN FD.

However, R10 must remain an inspection/review package only. A KiCad DRC-clean PCB is not enough here because the design is PCB-first, lacks an authoritative schematic, and still has power, protection, default-state, layout, and documentation blockers.

## Hard blockers before any JLCPCB order

1. Create a real `.kicad_sch` and run ERC from a schematic-driven KiCad project.
2. Fix TLIN1029 VSUP decoupling: C7 must decouple `+12V_PROTECTED` / U4 VSUP to GND, not `+5V_REGULATED`.
3. Add selectable/DNP LIN commander pull-up: `+12V_PROTECTED -> diode -> 1 kΩ -> LIN_BUS`, with a jumper/DNP that cannot bypass the 1 kΩ resistor.
4. Add `LIN_EN -> 100 kΩ -> GND` so the LIN transceiver defaults disabled during reset/boot.
5. Add safe-default CAN standby pull-ups: `CAN_A_STBY/XSTBY -> 10 kΩ -> +3.3 V` and `CAN_B_STBY/XSTBY -> 10 kΩ -> +3.3 V`.
6. Add SPI chip-select pull-ups: `CANFD_A_NCS -> 10 kΩ -> +3.3 V` and `CANFD_B_NCS -> 10 kΩ -> +3.3 V`.
7. Connect the LM2596 TO-263 thermal tab pad explicitly to GND.
8. Redo the buck/power routing with appropriate copper width and short input/switch/output current loops.
9. Add GND pours on both layers, with stitching vias and controlled return paths.
10. Move decoupling capacitors directly next to their IC power pins, preferably on the same side as each IC.
11. Move MCP2518FD crystal/load-cap networks next to U6/U7, ideally on the same side, and finalize crystal load capacitance instead of leaving `VERIFY_CL` values.
12. Resolve USB/VIN power isolation: at minimum document Teensy VUSB/VIN trace cut; preferably add a VIN selector or proper power-path/ideal-diode arrangement.
13. Add CAN A, CAN B, LIN, and K-line ESD/TVS protection near the connector/pigtail entry.
14. Reduce DIP-switch user-error risk: add hard silkscreen warnings/truth table and consider 1-of-N selection, jumper shunts, series resistors, or analog muxes for LIN/K and CAN routing.
15. Regenerate BOM from the schematic/PCB after these changes, then re-run ERC, DRC, Gerbers, drill, and package checks.

## Correct order guidance

Do **not** send `R10_TRUE_DUAL_CANFD_JLCPCB_GERBERS.zip` to JLCPCB.

Do **not** order R10 as-is.

Next manufacturable target should be **R10A/R11**, after the blockers above are fixed and verified.

## Current interpretation

R10 is a useful proof that the true dual-CAN-FD architecture is now correct. It is not a fabrication candidate.

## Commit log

2026-06-21 Add R5 pigtail DIP-switch manufacturing candidate
    [BOM_R5_PIGTAIL_DIPSWITCH.csv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]
2026-06-21 Add R6 complete-power procurement candidate
    [BOM_R6_PROCUREMENT_EU.csv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]
2026-06-30 Publish R11 prototype manufacturing candidate
    [teensy-41-true-dual-canfd-lin-r11_JARVIS_ROUTED_CLEAN_V2_GND_STITCH-B_Courtyard.gbr, teensy-41-true-dual-canfd-lin-r11_JARVIS_ROUTED_CLEAN_V2_GND_STITCH-B_Cu.g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]
